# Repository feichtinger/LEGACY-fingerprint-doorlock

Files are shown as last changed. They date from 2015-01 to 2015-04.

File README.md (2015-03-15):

# Fingerprint Doorlock
## Overview
A simple electronic doorlock using a fingerprint sensor. 

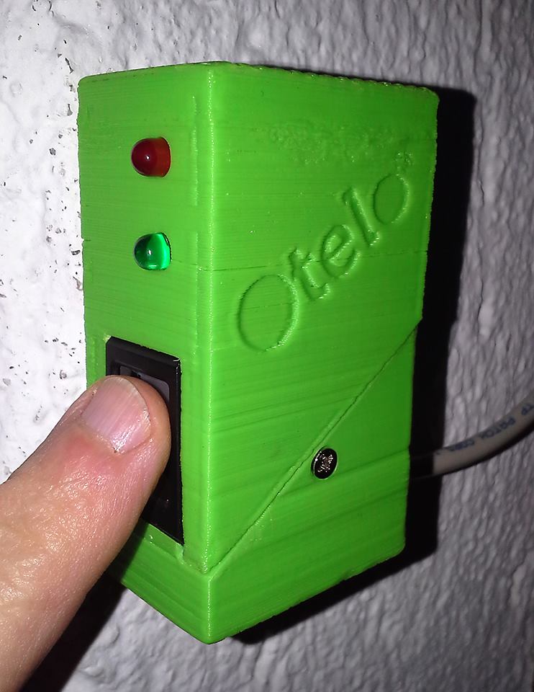
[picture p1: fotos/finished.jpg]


This project uses a ZFM-20 series fingerprint sensor to implement access controll (to a building or room) using an electrical doorlock (e.g. magnetic door buzzer).

All fingerprints can be managed by a simple GUI called Fingerprint-Manager or simply over a serial terminal.

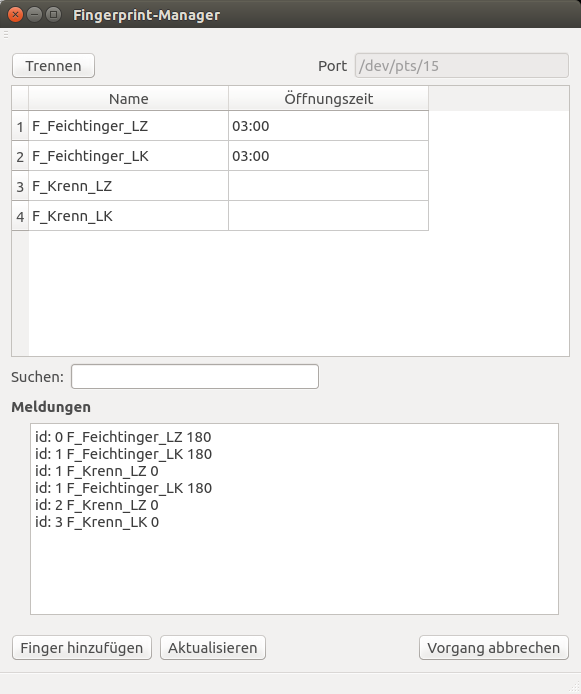
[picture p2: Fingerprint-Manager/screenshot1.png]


## Features
* easy access without a key, card or code (cannot be lost or forgotten)
* up to 1000 fingers can be enrolled
* whole day access option (keep the door open during events etc.)
* easy administration using the Fingerprint-Manager
* logfiles about every access (optional)

## Bill of materials
* EVK1101 Eval-Board from Atmel (a different board with an AVR32 controller might work as well)
* a ZFM-20 series fingerprint sensor e.g.
[from ebay](http://www.ebay.at/itm/Optical-Finger-print-Reader-Fingerprint-Sensor-Module-for-Arduino-Locks-/121298397934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)
* magnetic door buzzer (I took this one [from Reichelt](http://www.reichelt.de/T-R-FFNER-1B/3/index.html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))
* power supply 9VDC, 1.5A (e.g. [from Reichelt](http://www.reichelt.de/Festspannungsnetzteile/SNT-2250-9V/3/index.html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))
* a SD-card for the EVK1101 (capacity does not matter)
* a distribution box for the controller board
* some installation material (cables, cable channel, screws ...)
* some electronic parts from the junk box (transistor, diode, resistor, veroboard,...)

optional:

* a realtime clock module (for logfiles)
* a weather-proof button (for whole day access)

## System Components
### Fingerprintsensor
The ZFM sensor is placed in a custom housing which can easily be produced using an 3D printer (and a little bit of manual work). The housing also includes a red and a green LED and optionally a button for whole day access (see below).

The sensor should be placed on the outside next to the door and is connected to the controller board with a 7-pole cable (you can use a piece of ethernet cable for this).

### Controller Board
The controller consists of the EVK1101 and some additional electronics:

* a little PWM step down circuit (transistor + diode) to drive the buzzer
* connectors for fingerprintsensor and buzzer
* a USB to serial converter

Of course the controller board needs to be placed **behind** the door in a closed housing (you can use an distribution box for this).

The 9V power supply is directly connected to the EVK1101. Be carefull to choose a power supply that privides enough current for the buzzer. This might also be temperature dependent so better measure the buzzer current at 9V and choose a bigger power supply to be on the save side. 1.5A fits for my buzzer.

### Magnetic Door Buzzer
The buzzer only releases the falling latch, so the lock bar always has to be pulled back.

The buzzer might get warm when it is activated for a longer period of time (especially when using the whole day access). The firmware tries to reduce the power dissipation of the buzzer by reducing the holding current to 50% of starting current. Be shure that these settings work for your buzzer. (The buzzer has to open savely but must not get too hot.)

The buzzer is driven by the controller board. Ensure that the connecting cable is not accessible from the outside. If someone gets access to this cable he could easily open the door!

### PC
The normal operation (entering the door) is managed with with the above components only. But for enrolling new fingers, deleting fingers or to change settings a PC is necessary. You can either use a simple serial terminal software (e.g. cutecom) or you can use the Fingerprint-Manager.

### Realtime clock
I used the MCP7940N, a realtime clock made for 32.768kHz tuning forks with battery backup (thanks to Pointhi). I made a small PCB for the chip and its components with KiCad. It can be plugged directly into the TWI (=I²C) interface on the EVK1101.
Using the realtime clock it is possible to write log files on the SD card as it keeps the time also while the power is down or after resetting the system. This also helps at debugging.

## Netlist
There is no explicit schematic for the whole circuit but there is kind of a netlist ("netlist.ods") so you know which cable to connect to which pin. There are some slightly but necessary modifications on the EVK1101, don't forget about them!

## Software
### preparing the AVR32 toolchain
You need a bunch of software to compile the firmware for the EVK1101 and load it on the controller. This is called the toolchain. I will describe how to install the toolchain for Linux (in my case Ubuntu 14.04), if you are using windows it might be enough to install the AVR32-Studio (or maybe not), if you like to use a Mac, go somewhere else!

Create a folder on your disk for the toolchain anywhere you want, I will call it '~/AVR32_toolchain/'.

First of all we need the compiler, so go to the [Atmel-Website](http://www.atmel.com/tools/ATMELAVRTOOLCHAINFORLINUX.aspx) and download the "Atmel AVR 32-bit Toolchain 3.4.2 - Linux 64-bit" if your OS is 64-Bit. Unpack it into '~/AVR32_toolchain/'. The folder should be called "avr32-gnu-toolchain-linux_x86_64/".

Next we need the header files, so go back and download the "Atmel AVR 8-bit and 32-bit Toolchain (3.4.2) 6.1.3.1475 - Header Files". Unpack it into '~/AVR32_toolchain/' and remove the version from the folder name so the folder is called "atmel-headers/".

We also need the so called software framework so go [here](http://www.atmel.com/tools/avrsoftwareframework.aspx?tab=overview), download an unpack to '~/AVR32_toolchain/' and remove the version so the folder is called "asf/".

We are nearly finished, the last thing we need as a little programm to download the firmware to the controller, this is called dfu-programmer. Download from [Github](https://github.com/dfu-programmer/dfu-programmer), unpack in '~/AVR32_toolchain/' and rename the folder to "dfu-programmer/".

We need to compile this one so open a terminal in the folder and enter:

```
./bootstrap.sh
./configure
make
```
dfu-programmer needs access to the USB port, to enable this you have to copy the file "avr32_dfu.rules" to "/etc/udev/rules.d/". Also you have to join the group "plugdev":
`sudo usermod -aG plugdev username`  (replace 'username' by your username)

### build the firmware
To build the firmware you first have to tell the makefile where to find the toolchain, so open the makefile and edit the `TOOLCHAIN` makro (line 20) to your toolchain path.

Then call `make` to build the firmware.

Annoyingly Atmel seams to change the structure of their software framework a little bit in each revision so it might be possible that you need to change the makefile to get the firmware to build without errors.

To download the firmware you have to connect the USB-cable to the EVK1101 and turn it on. Then you have to switch the controller into bootloader mode. To do so, hold the joystick button on the EVK1101 pushed down and then press the reset button. (Now you should see a device typically called /dev/ttyACM0 in your Linux filesystem.)

To download the firmware finally call `make flash`.

Now you can connect a serial cable to the controller (baudrate 115200) and open a serial terminal (e.g. cutecom). When you press the reset button you should see a message from the firmware.

### prepare the SD card
The SD card is used to store the fingerprint database and the logfiles. The capacity of the SD-card does not realy matter, so just pick one from an old digicam for example. 

Format the SD card with FAT32. Create a file "users.txt" and a folder "logfiles".

### build the Fingerprint-Manager
The Fingerprint-Manager is a simple GUI written in Qt-5 that allows you to easily enroll and manage fingerprints. To build the Fingerprint-Manager you need to install Qt-Creator.

`sudo apt-get install qt-creator`

You also need the serial port module for Qt-5

`sudo apt-get install libqt5serialport5-dev`

Now you can simply open the Qt project (Fingerprint-Manager.pro) with Qt-Creator and build it.

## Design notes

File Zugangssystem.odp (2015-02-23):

## Fingerabdruck Zugangssystem


## Warum ein neues Zugangssystem?

- Schlüssel gingen verloren/wurden gestohlen
- viele direkte und indirekte Nutzer (hoher Verwaltungsaufwand)
- viele Nutzer hatten daher (bis jetzt) keinen Schlüssel
- schwierige Situation bei (öffentlichen) Veranstaltungen
- Fluchtwegsituation!

## Warum Fingerabdrücke

- biometrisches System
- kann man nicht verlieren oder vergessen
- einfache Handhabung
- Zutrittsberechtigung kann jederzeit wieder gesperrt werden
- Fingerabdruck-Sensoren sind relativ kostengünstig

## Aufbau des neuen Systems

- Vor der Tür ist der Sensor im eigenen Gehäuse
  - grüne LED: Zugang gestattet, Tür ist offen
  - rote LED: Zugang nicht gestattet
  - Taste für Ganztageszugang
- Die eigentliche Steuerung ist hinter der Tür
- Ein Türmagnet gibt die „Falle“ frei
- Die Verwaltung erfolgt über einen PC

## Was kann das neue System?

- Es gibt normale Benutzer und „Gruppenleiter“
- beide können „normal“ hineingehen: Finger auf Sensor legen -> Tür geht für 3s auf.
- Gruppenleiter können die Tür auch für eine längere Zeit unversperrt lassen -> „Ganztageszugang“
- Dies ist vor allem für Veranstaltungen gedacht

## Ganztageszugang

1. Taste auf der Rückseite des Sensors gedrückt halten
2. Finger auf Sensor legen
- Die Tür bleibt nun offen (erkennbar an der grünen LED)
- Nach dem gleichen Schema kann die Tür auch wieder verschlossen werden.
- Nach einer maximalen Öffnungszeit (für jeden Gruppenleiter individuell) verschließt sich die Tür selbstständig.

## Registrierung

- erfolgt direkt vor Ort mit PC
- Der Finger sollte sauber sein
- Finger flach auf den Sensor legen
- Der Sensor sollte möglichst ganz bedeckt sein.
- Empfehlung: mindestens 2 Finger

## Sicherheit

- Auch Fingerabdrücke können mit einigem Aufwand gefälscht werden.
- Zunächst bräuchte man aber einen gültigen Fingerabdruck.
- Es gibt einfachere Wege sich Zugang zu verschaffen...

## Tipps und Hinweise

- Verwische den Fingerabdruck gleich wieder nach dem Scannen.
- Jeder Gruppenleiter ist (nur) für seine Veranstaltung verantwortlich.
- Wenn die grüne LED bereits leuchtet ist wahrscheinlich eine Veranstaltung im Gange.
- Benutze deine Rechte also nicht um andere Veranstaltungsbesucher auszusperren.
- Verschließe die Tür nicht mit dem Schlüssel. (Das Zylinderschloss ist nur für Notfälle gedacht.)

## Protokollierung

- Jeder Zugang (Name, Datum, Uhrzeit) wird elektronisch im System protokolliert.
- Diese Daten werden nur im Ausnahmefall (Diebstahl, Vandalismus, ...) vom Hausverwalter ausgelesen und nicht veröffentlicht.

## Wer entwickelt das Projekt?

- Das Zugangssystem wird vom Elektronik-Node im OTELO entwickelt.
- Das Projekt ist vollständig open-source d.h. jeder kann sich sämtliche Entwicklungsdaten (Quellcode, Schaltpläne, CAD-Daten, ...) herunterladen und gratis verwenden.
- Es gibt bereits Interesse von anderen OTELOs

## Mitwirkende

- Friedrich Feichtinger:
  - Entwicklung, Programmierung, Betreuung
- Karl Zeilhofer:
  - CAD, Gehäusekonstruktion
- Bernhard Brunner:
  - Konzept, Betreuung
- Fabian Krenn:
  - Montage
- Stefan Schallmeiner
  - Verkabelung
- Lukas Ebner
  - Elektronik
- Thomas Pointhuber
  - Debugging

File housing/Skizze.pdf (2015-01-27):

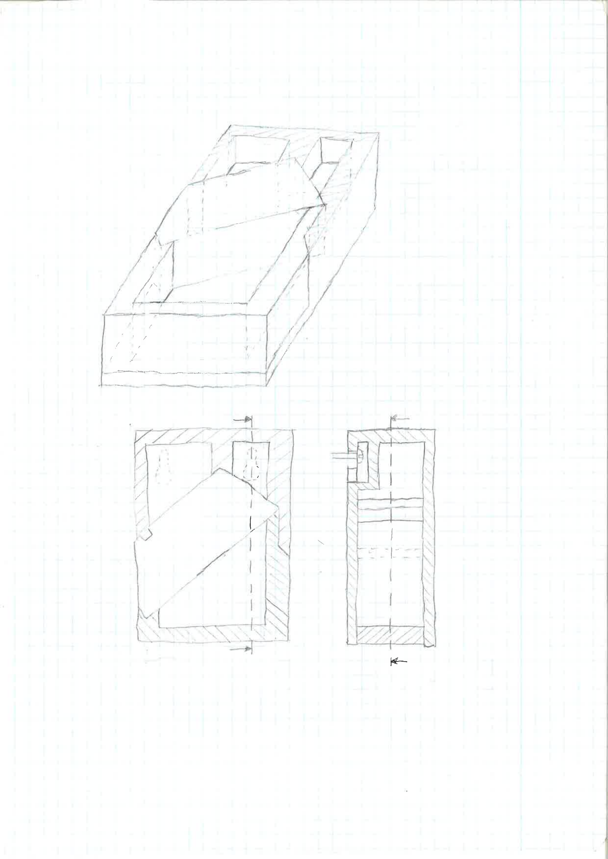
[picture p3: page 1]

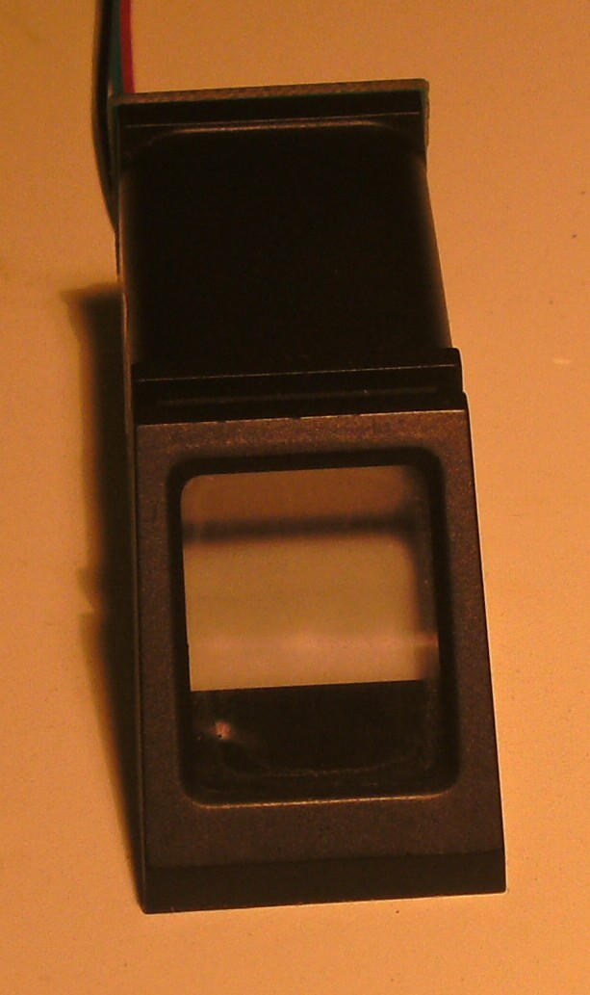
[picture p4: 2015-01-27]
fotos/BILD0147.JPG

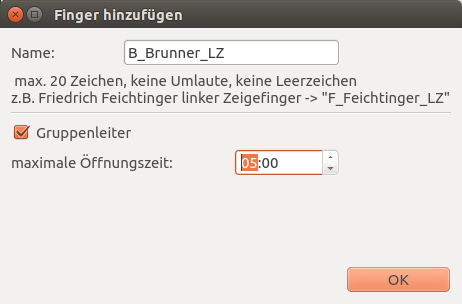
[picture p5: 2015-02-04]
Fingerprint-Manager/screenshot2.png

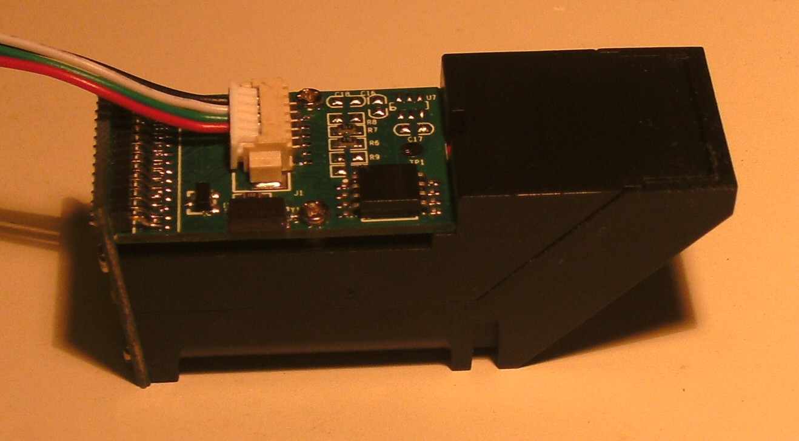
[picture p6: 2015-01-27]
fotos/BILD0150.JPG

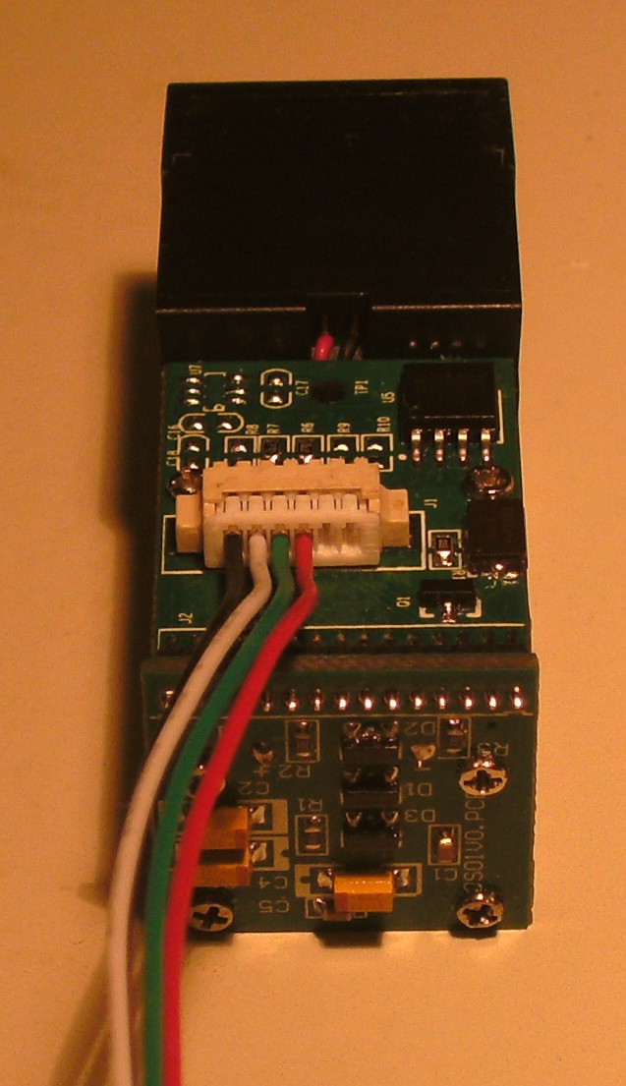
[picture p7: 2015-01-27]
fotos/BILD0149.JPG

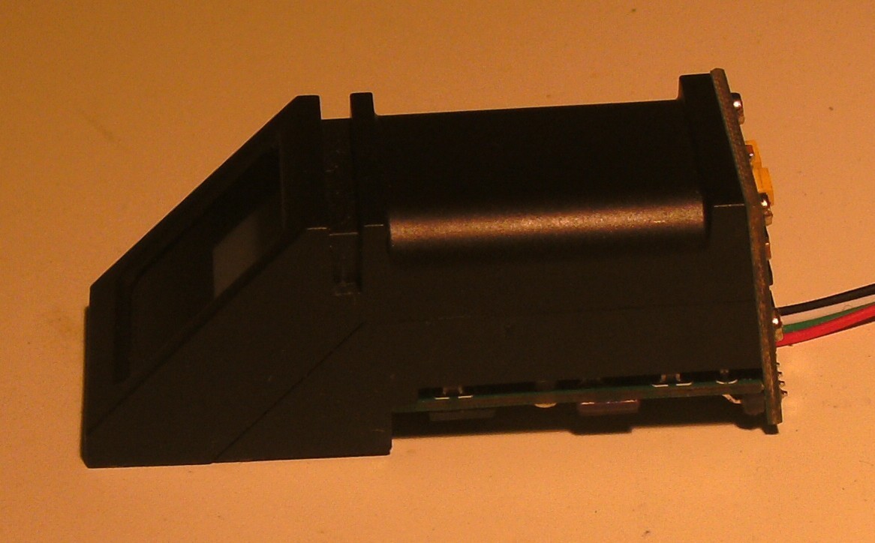
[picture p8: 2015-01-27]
fotos/BILD0144.JPG

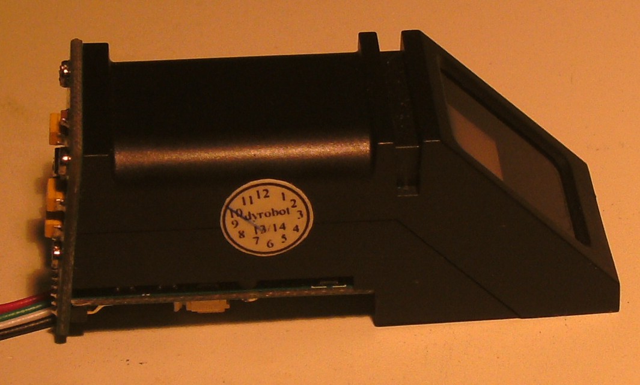
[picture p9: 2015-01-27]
fotos/BILD0146.JPG

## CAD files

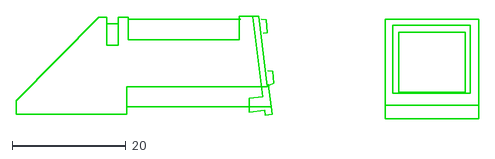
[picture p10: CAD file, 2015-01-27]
housing/drawing.dxf
81.5 x 18.0

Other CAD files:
housing/housing-3d.skp

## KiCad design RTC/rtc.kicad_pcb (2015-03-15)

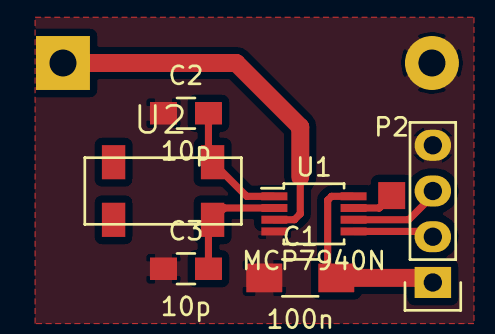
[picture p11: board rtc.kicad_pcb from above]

Board: 2 copper layers, 8 parts (1 on the bottom side), 8 nets.

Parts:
BT1: BATTERY; keystone_103
C1: 100n; C_1206_HandSoldering
C2, C3: 10p; C_0805_HandSoldering
P1: CONN_01X04; Pin_Header_Straight_1x04
P2: CONN_01X01; Measurement_Point_Square-SMD-Pad_Small
U1: MCP7940N; MSOP-8_3x3mm_Pitch0.65mm
U2: 32.768kHz; FOX-tuning-fork

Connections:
+3V3: C1.2, P1.1, U1.8
GND: BT1.2, C1.1, C2.1, C3.1, P1.4, U1.4
unnamed: BT1.1, U1.3
unnamed: C2.2, U1.1, U2.4
unnamed: C3.2, U1.2, U2.1
unnamed: P1.2, U1.5
unnamed: P1.3, U1.6
unnamed: P2.1, U1.7

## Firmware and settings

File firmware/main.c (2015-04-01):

// generic C
#include <stdio.h>
#include <stdbool.h>
#include <stdint.h>
#include <string.h>
#include <stdarg.h>
#include <time.h>

// ATMEL software framework
#include <avr32/io.h>
#include "board.h"
#include <intc.h>
#include <pm.h>
#include <usart.h>
#include <gpio.h>
#include <spi.h>
#include <cycle_counter.h>
#include <led.h>

// SD/MMC & FAT
#include <sd_mmc_spi.h>
#include <sd_mmc_spi_mem.h>
#include <fsaccess.h>
#include "conf_sd_mmc_spi.h"

// my modules
#include "main.h"
#include "fingerprint.h"
#include "command_shell.h"
#include "database.h"
#include "rtc.h"


/*
 * fingerprint doorlock
 * 
 * Fritz Feichtinger, 2014
 * 
 * A ZFM-20 series fingerprint sensor is used to open a door lock (or something else).
 * This sensor does a lot of work out of the box, not only image capturing but also feature extraction,
 * maintaining a fingerprint library, searching and matching. The ZFM-20 uses a serial port to communicate with the MCU.
 * So (nearly) all we have to do is set up a serial port to the sensor and tell it what to do.
 * In NORMAL-mode the sensor is used to scan and match a finger and unlock the door if the detected finger is known.
 * To enroll new fingers we can switch to ENROLL-mode. After a finger was detected we switch back to NORMAL-mode.
 * 
 * The ZFM-20 does NOT store any additional information about the fingerprint, i.e. a name.
 * So we have to store this information (which ID belongs to whos finger) on our own.
 * This makes life a lot easier in the case we want to delete ones access permission one day.
 * Also we can log all activities to a file with usefull information (who entered the building at which time) if we want.
 * 
 * All processes can be controlled by PC connected to a second serial port.
 * 
 */



/* global variables */

// operation modes
volatile enum {NORMAL, ENROLL, DELETE, DELETE_ALL, RESTORE} mode=NORMAL;

// temporary variables used for enroll, delete, restore,...
volatile uint8_t temp_slot=1;
volatile uint16_t temp_id=0;
char temp_name[MAXSTRLEN+1];
uint16_t temp_openTime=0;

// whole day access
time_t doorClosingTime=0;		// time when WDA is disabled, 0 means no WDA


/* private functions */
void normal_mode();
void enroll_mode();
void delete_mode();
void delete_all_mode();
void restore_mode();

void sd_mmc_resources_init(void);


/*
 * interrupt handler for usart
 * give received characters to command shell
 */
__attribute__((__interrupt__)) static void pc_usart_int_handler(void)
{
	if(usart_overrun_error(&PC_USART) || usart_framing_error(&PC_USART))
	{
		usart_reset_status(&PC_USART);
		return;
	}
	
	int c;
	usart_read_char(&PC_USART, &c);
	
	// cast to 8-bit
	uint8_t ch=c;
	shell_feedChar(ch);
}


/*
 * main routine:
 * initialize hardware and then start main loop
 */
int main(void)
{
	/*
	 * initialize hardware
	 */
	 
	Disable_global_interrupt();
	
	// switch to external quartz oscillator
	pm_switch_to_osc0(&AVR32_PM, FOSC0, OSC0_STARTUP);
	
	// init watchdog (~18.7s)
	AVR32_WDT.ctrl = (0x55<<AVR32_WDT_KEY)|(20<<AVR32_WDT_PSEL)|(1<<AVR32_WDT_EN);
	AVR32_WDT.ctrl = (0xAA<<AVR32_WDT_KEY)|(20<<AVR32_WDT_PSEL)|(1<<AVR32_WDT_EN);
	
	// enable BOD, 1.61V
	AVR32_PM.bod = (0x55<<AVR32_WDT_KEY)|(1<<AVR32_PM_BOD_CTRL)|(1<<AVR32_PM_BOD_HYST)|(0b011111<<AVR32_PM_BOD_LEVEL);
	AVR32_PM.bod = (0xAA<<AVR32_WDT_KEY)|(1<<AVR32_PM_BOD_CTRL)|(1<<AVR32_PM_BOD_HYST)|(0b011111<<AVR32_PM_BOD_LEVEL);
	
	// configure LED0, LED1, LED2
	AVR32_GPIO.port[0].gpers = (1<<7)|(1<<8)|(1<<21);
	AVR32_GPIO.port[0].oders = (1<<7)|(1<<8)|(1<<21);
	AVR32_GPIO.port[0].ovrs  = (1<<21);		// turn off LED2
	
	GREEN_LED_OFF;
	RED_LED_OFF;
	
	
	// init PC USART
	static const gpio_map_t PC_USART_GPIO_MAP =
	{
		{AVR32_USART1_RXD_0_0_PIN, AVR32_USART1_RXD_0_0_FUNCTION},
		{AVR32_USART1_TXD_0_0_PIN, AVR32_USART1_TXD_0_0_FUNCTION}
	};
	gpio_enable_module(PC_USART_GPIO_MAP, 2);

	static const usart_options_t PC_USART_OPTIONS =
	{
		.baudrate     = 115200,
		.charlength   = 8,
		.paritytype   = USART_NO_PARITY,
		.stopbits     = USART_1_STOPBIT,
		.channelmode  = USART_NORMAL_CHMODE
	};
	usart_init_rs232(&PC_USART, &PC_USART_OPTIONS, FOSC0);
	
	
	// init fingerprint USART
	static const gpio_map_t FP_USART_GPIO_MAP =
	{
		{AVR32_USART0_RXD_0_1_PIN, AVR32_USART0_RXD_0_1_FUNCTION},
		{AVR32_USART0_TXD_0_1_PIN, AVR32_USART0_TXD_0_1_FUNCTION}
	};
	gpio_enable_module(FP_USART_GPIO_MAP, 2);
	
	static const usart_options_t FP_USART_OPTIONS =
	{
		.baudrate     = 57600,
		.charlength   = 8,
		.paritytype   = USART_NO_PARITY,
		.stopbits     = USART_1_STOPBIT,
		.channelmode  = USART_NORMAL_CHMODE
	};
	usart_init_rs232(&FP_USART, &FP_USART_OPTIONS, FOSC0);

	// init interrupt vectors.
	INTC_init_interrupts();
	INTC_register_interrupt(&pc_usart_int_handler, AVR32_USART1_IRQ, AVR32_INTC_INT0);
	
	// Initialize and enable interrupt, seems to be needed by TWI...?
	cpu_irq_enable();

	// Enable USART Rx interrupt.
	AVR32_USART1.ier = AVR32_USART_IER_RXRDY_MASK;
	
	
	// Initialize SD/MMC driver resources: GPIO, SPI and SD/MMC.
	sd_mmc_resources_init();
	
	
	// init PWM for magnet opener (PA22 -> PWM6)
	AVR32_GPIO.port[0].gperc = (1<<22);
	AVR32_GPIO.port[0].pmr0s = (0<<22);
	AVR32_GPIO.port[0].pmr1s = (0<<22);
	
	AVR32_PWM.channel[6].cmr = (1<<AVR32_PWM_CPOL);	// set polarity to high (cdty==0 means output is low)
	AVR32_PWM.channel[6].cprd = 1000;				// f_PWM=12kHz
	AVR32_PWM.channel[6].cdty = 0;					// start with duty=0
	AVR32_PWM.ena = (1<<AVR32_PWM_ENA_CHID6);		// enable PWM
	
	/*
	 * hardware initialized, start up software
	 */
	
	
	printf("\n\n");
	printf("*** fingerprint doorlock ***\n");
	
	
	// wait for fingerprint-sensor to start up
	wait_ms(500);
	
	// init realtime clock
	printf("check for realtime clock...");
	if(RTC_Init(FOSC0))
	{
		printf("OK\n");
	}
	else
	{
		printf("ERROR: could not init realtime clock\n");
		return 0;
	}
	
	
	// init SD-card
	printf("check for SD card...");
	if(sd_mmc_spi_mem_check())
	{
		printf("OK\n");
	}
	else
	{
		printf("ERROR: no SD card detected\n");
		return 0;
	}
	
	printf("check if SD card is ready...");
	if(mem_test_unit_ready(LUN_ID_SD_MMC_SPI_MEM) == CTRL_GOOD)
	{
		printf("OK\n");
	}
	else
	{
		printf("ERROR: SD card not ready\n");
		return 0;
	}
	
	uint32_t cap;
	mem_read_capacity(LUN_ID_SD_MMC_SPI_MEM, &cap);
	printf("SD card capacity: %d MB\n", (int)((cap + 1) >> (20 - FS_SHIFT_B_TO_SECTOR)));
	
	// init filesystem
	b_fsaccess_init();
	
	// read database from SD-card
	if(!db_readFromCard())
	{
		printf("ERROR: could not read file\n");
		return 0;
	}
	
	// check reset cause
	switch(pm_get_reset_cause(&AVR32_PM))
	{
		case 1<<AVR32_PM_RCAUSE_POR:
			writeLogEntry("Power-On Reset");
			break;
		case 1<<AVR32_PM_RCAUSE_BOD:
			writeLogEntry("Brownout Reset");
			break;
		case 1<<AVR32_PM_RCAUSE_EXT:
			writeLogEntry("External Reset");
			break;
		case 1<<AVR32_PM_RCAUSE_WDT:
			writeLogEntry("Watchdog Timer Reset");
			break;
		default:
			writeLogEntry("other reset cause");
	}
	
	
	writeLogEntry("system ready...");
	
	// enable interrupts
	Enable_global_interrupt();
	
	
	// Let the show begin ...
	

	/* main loop */
	while(true)
	{
		KICK_DOG;
		
		// scan command line
		shell_scan();
		
		switch(mode)
		{
			case NORMAL:
			{
				normal_mode();
				break;
			}
			case ENROLL:
			{
				enroll_mode();
				break;
			}
			case DELETE:
			{
				delete_mode();
				break;
			}
			case DELETE_ALL:
			{
				delete_all_mode();
				break;
			}
			case RESTORE:
			{
				restore_mode();
				break;
			}
		}
		
		
		// check for whole day access timeout
		if(doorClosingTime!=0 && time(NULL)>=doorClosingTime)
		{
			doorClosingTime=0;
			GREEN_LED_OFF;
			LOCK;
			writeLogEntry("whole day access time out");
		}
	}
}



/****************************************************************************************/
/*							operation modes (main context)								*/
/****************************************************************************************/


/*
 * normal operation (open door for authorized users)
 * 
 * How it works:
 * Try to find a finger, scan it, extract template and compare with database.
 * If anything does not work as expected simply abort execution (and print error), it will get restarted by the main loop.
 */
void normal_mode()
{
	// clear temp data
	temp_slot=1;
	temp_id=0;
	temp_name[0]='\0';
	
	uint8_t confirm;	// use this for confirmation codes
	
	// try to find finger on camera
	confirm=fp_getImage();
	if(confirm!=FINGERPRINT_NOFINGER)
	{
		if(confirm!=FINGERPRINT_OK)
		{
			fp_error(confirm);
			return;
		}
		
		// try to create feature file from image
		confirm=fp_image2Tz(1);
		if(confirm!=FINGERPRINT_OK)
		{
			fp_error(confirm);
			return;
		}
		
		// try to find matching template
		uint16_t id=0;
		uint16_t score=0;
		confirm=fp_search(1, 0, FINGERPRINT_MAXFINGERS, &id, &score);
		if(confirm==FINGERPRINT_OK)
		{
			// found a match!
			if(WDA_BUTTON_PRESSED)	// check for whole day access button
			{
				if(db_getOpenTime(id)>0)
				{
					// user is group leader -> authorized
					if(doorClosingTime!=0)
					{
						// disable whole day access
						doorClosingTime=0;
						GREEN_LED_OFF;
						LOCK;
						writeLogEntry("whole day access disabled by %s", db_getName(id));
						wait_ms(DOOR_OPEN_TIME);
					}
					else
					{
						// enable whole day access
						doorClosingTime=time(NULL)+db_getOpenTime(id)*60;		// calculate door closing time
						
						GREEN_LED_ON;
						UNLOCK;
						writeLogEntry("whole day access enabled by %s", db_getName(id));
						wait_ms(DOOR_OPEN_TIME);
						KEEP_UNLOCKED;
					}
				}
				else
				{
					// user is normal user -> not authorized to change whole day access
					RED_LED_ON;
					writeLogEntry("%s is not allowed to change whole day access", db_getName(id));
					wait_ms(ACCESS_DENIED_TIMEOUT);
					RED_LED_OFF;
				}
			}
			else if(doorClosingTime==0)
			{
				// normal access when WDA is disabled
				GREEN_LED_ON;
				UNLOCK;
				writeLogEntry("access granted for %s, score: %d", db_getName(id), score);
				wait_ms(DOOR_OPEN_TIME);
				GREEN_LED_OFF;
				LOCK;
			}
			
			return;
		}
		else if(confirm==FINGERPRINT_NOTFOUND)
		{
			// no matching template
			RED_LED_ON;
			writeLogEntry("Access denied, please try again.");
			wait_ms(ACCESS_DENIED_TIMEOUT);
			RED_LED_OFF;
			return;
		}
		else
		{
			fp_error(confirm);
			return;
		}
	}
}


/*
 * enroll new finger and store in database
 * 
 * How it works:
 * Try to scan and featurize 2 fingerprints (in slot 1 and 2), combine them into template file and store in database.
 * The generated template file is uploaded and stored on SD-card, this is for backup only.
 * If anything does not work as expected simply abort execution (and print error), it will get restarted by the main loop. (as long as in ENROLL mode)
 * after success switch back to NORMAL mode.
 */
void enroll_mode()
{
	uint8_t confirm;
	
	// try to find finger on camera
	confirm=fp_getImage();
	if(confirm!=FINGERPRINT_NOFINGER)
	{
		if(confirm!=FINGERPRINT_OK)
		{
			fp_error(confirm);
			return;
		}
		
		// try to create feature file from image
		confirm=fp_image2Tz(temp_slot);
		if(confirm!=FINGERPRINT_OK)
		{
			fp_error(confirm);
			return;
		}
		
		if(temp_slot==1)
		{
			// slot 1 successfull, continue with slot 2
			temp_slot=2;
			return;
		}
		if(temp_slot==2)
		{
			// slot 2 successfull, generate template
			temp_slot=1;
			confirm=fp_createModel();
			if(confirm!=FINGERPRINT_OK)
			{
				fp_error(confirm);
				return;
			}
			
			// store template at next free id
			confirm=fp_storeModel(1, temp_id);
			if(confirm!=FINGERPRINT_OK)
			{
				fp_error(confirm);
				return;
			}
			
			// upload fingerprint template file from sensor
			uint8_t temp_file[FINGERPRINT_TEMPSIZE];
			
			confirm=fp_upChar(1, temp_file);
			if(confirm!=FINGERPRINT_OK)
			{
				fp_error(confirm);
				return;
			}
			
			// finger enrolled, store in database, save template on SD-card
			if(db_addFinger(temp_name, temp_id, temp_openTime, temp_file))
			{
				writeLogEntry("%s successfully enrolled, id=%d", temp_name, temp_id);
			}
			
			//wait_ms(ACCESS_DENIED_TIMEOUT);
			// success, back to normal mode
			mode=NORMAL;
		}
	}
}


/*
 * delete a finger
 */
void delete_mode()
{
	// try to delete template on sensor
	uint8_t confirm;
	confirm=fp_deleteModel(temp_id, 1);
	if(confirm!=FINGERPRINT_OK)
	{
		fp_error(confirm);
		mode=NORMAL;
		return;
	}
	
	// remove entry from database (but not the template file!)
	if(db_delFinger(temp_id))
	{
		writeLogEntry("finger successfully deleted, id=%d", temp_id);
	}
	
	// success, back to normal mode
	mode=NORMAL;
}


/*
 * delete ALL fingers (handle with care)
 */
void delete_all_mode()
{
	uint8_t confirm;
	confirm=fp_emptyDatabase();
	if(confirm!=FINGERPRINT_OK)
	{
		fp_error(confirm);
		mode=NORMAL;
		return;
	}
	
	if(db_deleteAllFingers())
	{
		writeLogEntry("all fingers deleted successfully");
	}
	mode=NORMAL;
}

/*
 * This is for special cases only
 * If the template file on the sensor should get lost you can restore it from SD-card
 */ 
void restore_mode()
{
	uint8_t temp_file[FINGERPRINT_TEMPSIZE];
	uint8_t confirm;
	
	// read template file from SD-card
	if(!db_restoreFinger(temp_name, temp_file))
	{
		mode=NORMAL;
		return;
	}
	
	// download template to sensor
	confirm=fp_downChar(1, temp_file);
	if(confirm!=FINGERPRINT_OK)
	{
		fp_error(confirm);
		mode=NORMAL;
		return;
	}
	
	// store template in sensor database
	confirm=fp_storeModel(1, temp_id);
	if(confirm!=FINGERPRINT_OK)
	{
		fp_error(confirm);
		mode=NORMAL;
		return;
	}
	
	writeLogEntry("finger successfully restored");
	mode=NORMAL;
}


/****************************************************************************************/
/*						PC commands	(command shell context)								*/
/****************************************************************************************/


/*
 * call this to enroll a new finger
 */
void start_enroll(char *name, uint16_t openTime)
{
	// first, check the given string for possible errors
	uint8_t len=strlen(name);
	if(len==0)
	{
		writeLogEntry("ERROR: expected name for fingerprint!");
		return;
	}
	if(len>MAXSTRLEN)
	{
		writeLogEntry("ERROR: name is too long!");
		return;
	}
	if(db_findFinger(name)>=0)
	{
		writeLogEntry("ERROR: this name already exists, choose a different name");
		return;
	}
	
	// check for free space
	int16_t id=db_findFirstFree();
	if(id<0)
	{
		writeLogEntry("ERROR: finger library is full!");
		return;
	}
	
	// check open time
	if(openTime>24*60)
	{
		writeLogEntry("ERROR: invalid open time");
		return;
	}
	
	writeLogEntry("enrolling finger, place finger on sensor and wait...");
	
	mode=ENROLL;
	temp_id=id;
	temp_openTime=openTime;
	strcpy(temp_name, name);
	
	// the rest happens in enroll_mode...
}


void start_delete(char *name)
{
	// check string
	uint8_t len=strlen(name);
	if(len==0)
	{
		writeLogEntry("ERROR: expected name for fingerprint!");
		return;
	}
	if(len>MAXSTRLEN)
	{
		writeLogEntry("ERROR: name is too long!");
		return;
	}
	int16_t id=db_findFinger(name);
	if(id<0)
	{
		writeLogEntry("ERROR: this name does not exist in library");
		return;
	}
	
	mode=DELETE;
	temp_id=id;
	strcpy(temp_name, name);
	
	// the rest happens in delete_mode...
}

void start_delete_all(void)
{
	mode=DELETE_ALL;
}


void start_restore(char* name)
{
	uint8_t len=strlen(name);
	if(len==0)
	{
		writeLogEntry("ERROR: expected name for fingerprint!");
		return;
	}
	if(len>MAXSTRLEN)
	{
		writeLogEntry("ERROR: name is too long!");
		return;
	}
	int16_t id=db_findFinger(name);
	if(id<0)
	{
		writeLogEntry("ERROR: this name does not exist in library");
		return;
	}
	
	mode=RESTORE;
	temp_id=id;
	strcpy(temp_name, name);
}


void abort_op()
{
	mode=NORMAL;
	temp_slot=1;
	writeLogEntry("aborted");
}




/****************************************************************************************/
/*									miscellaneous										*/
/****************************************************************************************/


void wait_ms(uint32_t time)
{
	cpu_delay_ms(time, FOSC0);
}


void sd_mmc_resources_init(void)
{
	// GPIO pins used for SD/MMC interface
	static const gpio_map_t SD_MMC_SPI_GPIO_MAP =
	{
		{SD_MMC_SPI_SCK_PIN,  SD_MMC_SPI_SCK_FUNCTION },  // SPI Clock.
		{SD_MMC_SPI_MISO_PIN, SD_MMC_SPI_MISO_FUNCTION},  // MISO.
		{SD_MMC_SPI_MOSI_PIN, SD_MMC_SPI_MOSI_FUNCTION},  // MOSI.
		{SD_MMC_SPI_NPCS_PIN, SD_MMC_SPI_NPCS_FUNCTION},  // Chip Select NPCS.
	};

	// SPI options.
	spi_options_t spiOptions =
	{
		.reg          = SD_MMC_SPI_NPCS,
		.baudrate     = 400000,
		.bits         = SD_MMC_SPI_BITS,          // Defined in conf_sd_mmc.h.
		.spck_delay   = 0,
		.trans_delay  = 0,
		.stay_act     = 1,
		.spi_mode     = 0,
		.modfdis      = 1
	};

	// Assign I/Os to SPI.
	gpio_enable_module(SD_MMC_SPI_GPIO_MAP,
					 sizeof(SD_MMC_SPI_GPIO_MAP) / sizeof(SD_MMC_SPI_GPIO_MAP[0]));

	// Initialize as master.
	spi_initMaster(SD_MMC_SPI, &spiOptions);

	// Set SPI selection mode: variable_ps, pcs_decode, delay.
	spi_selectionMode(SD_MMC_SPI, 0, 0, 0);

	// Enable SPI module.
	spi_enable(SD_MMC_SPI);

	// Initialize SD/MMC driver with SPI clock (PBA).
	sd_mmc_spi_init(spiOptions, FOSC0);
}



void writeLogEntry(const char* format, ...)
{
	FILE* logfile=NULL;
	va_list args;
	va_start(args, format);
	
	time_t t=time(NULL);						// get time from rtc
	//time_t t=0;
	struct tm * time_struct=localtime(&t);
	
	// one logfile per day
	char filename[31];
	strftime(filename, 30, "A:/logfiles/%Y_%m_%d.log", time_struct);
	
	// prepend time to string
	char string[101];
	strftime(string, 100, "<%H:%M:%S> ", time_struct);
	strcat(string, format);
	strcat(string, "\n");
	
	vprintf(string, args);				// write to serial port
	
	// open logfile
	logfile=fopen(filename, "a");
	if(logfile==NULL)
	{
		printf("ERROR: could not open logfile\n");
		return;
	}
	
	vfprintf(logfile, string, args);	// write to logfile
	va_end(args);
	
	fclose(logfile);
}


// dummy callback functions (workaround for bug in software framework)
void sd_mmc_spi_write_multiple_sector_callback(void* sector_buf)
{
	
}

void sd_mmc_spi_read_multiple_sector_callback(const void* sector_buf)
{
	
}

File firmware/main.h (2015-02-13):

#ifndef MAIN_H
#define MAIN_H

#include <stdint.h>
#include "board.h"

/* common constants */

#define FP_USART AVR32_USART0			// this USART is used for Fingerprintsensor
#define PC_USART AVR32_USART1			// this USART is used for PC

#define F_PBA	48000000				// PBA bus frequency

#define DOOR_OPEN_TIME			3000	// ms, time for which the door is unlocked after detecting matching finger
#define ACCESS_DENIED_TIMEOUT	1000	// ms, time to wait after "Access denied"
#define WDA_TIME				12		// hours, maximum time for whole day access


/* macros */

#define KICK_DOG	AVR32_WDT.clr=0			// 'kick' watchdog timer, only call this in main loop

#define WDA_BUTTON_PRESSED	(!(AVR32_GPIO.port[1].pvr&(1<<2)))	// true if whole-day-access button is pressed

#define GREEN_LED_ON		LED_Off(LED0)	// LED0 and LED1 are inverted
#define GREEN_LED_OFF		LED_On(LED0)
#define RED_LED_ON			LED_Off(LED1)
#define RED_LED_OFF			LED_On(LED1)
#define DCF_LED_ON			LED_On(LED2)
#define DCF_LED_OFF			LED_Off(LED2)

#define LOCK				AVR32_PWM.channel[6].cdty = 0			// magnet power off -> door closed
#define UNLOCK				AVR32_PWM.channel[6].cdty = 1000		// full voltage, only use a few seconds to release magnet
#define KEEP_UNLOCKED		AVR32_PWM.channel[6].cdty = 500			// reduced voltage to prevent magnet for overload, use after UNLOCK for whole day access


/* public functions */

void start_enroll(char *name, uint16_t openTime);
void start_delete(char *name);
void start_delete_all(void);
void start_restore(char* name);
void abort_op();

void wait_ms(uint32_t time);
void writeLogEntry(const char* format, ...);


#endif

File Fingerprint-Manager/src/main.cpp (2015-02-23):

#include "fingerprintmanager.h"
#include <QApplication>
#include <QTextCodec>
#include <QTranslator>
#include <QLocale>
#include <QLibraryInfo>
#include <QtDebug>

int main(int argc, char *argv[])
{
	QApplication a(argc, argv);
	//QTextCodec::setCodecForTr(QTextCodec::codecForName("UTF-8"));		// all messages in tr() are interpreted in UTF-8 so the file encoding for all source-files should be UTF-8 too.
    QCoreApplication::setOrganizationName("OTELO");
    QCoreApplication::setApplicationName("Fingerprint Manager");
	FingerprintManager w;
	w.show();
	
	// translation
    QTranslator qtTranslator;
	if(!qtTranslator.load("/usr/share/qt4/translations/qt_de.qm", QLibraryInfo::location(QLibraryInfo::TranslationsPath)))
	{
		qDebug() << "translation could not be loaded";
	}
    a.installTranslator(&qtTranslator);
	
	return a.exec();
}

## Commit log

2015-01-27 First Commit!
    [drawing.dxf, housing-3d.skp, netlist.ods]
2015-02-01 Fingerprint-Manager: first useable version
2015-02-04 fixed some bugs in Fingerprint-Manager
2015-02-13 added documentation
    [netlist.ods]
2015-03-14 removed DCF-module
    [netlist.ods, rtc.kicad_pcb, rtc.sch]
2015-03-15 some bugs at rtc fixed
    [rtc.kicad_pcb, rtc.sch]
2015-04-01 added brown out detection
    [main.c]
